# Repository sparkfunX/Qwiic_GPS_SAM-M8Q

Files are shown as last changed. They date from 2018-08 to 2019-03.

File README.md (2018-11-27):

SparkFun Ublox GPS Breakout - SAM-M8Q
===========================================================

SparkFun SAM-M8Q (https://www.sparkfun.com/products/15106)

[*SparkFun Ublox GPS Breakout - SAM-M8Q (SPX-15106)*](https://www.sparkfun.com/products/15106)

The SAM-M8Q is a small GNSS receiver from Ublox with an impressive number of configurations and the ability to communicate over I2C. 

Repository Contents
-------------------

* **/Documents** - Ublox datasheets and various whitepapers around RTK
* **/Hardware** - Eagle files

Documentation
--------------

* **[Installing an Arduino Library Guide](https://learn.sparkfun.com/tutorials/installing-an-arduino-library)** - Basic information on how to install an Arduino library.
* **[Arduino Library](https://github.com/sparkfun/SparkFun_Ublox_Arduino_Library)** - Arduino Library for the SparkFun Ublox GPS-RTK.

License Information
-------------------

This product is _**open source**_! 

Various bits of the code have different licenses applied. Anything SparkFun wrote is beerware; if you see me (or any other SparkFun employee) at the local, and you've found our code helpful, please buy us a round!

Please use, reuse, and modify these files as you see fit. Please maintain attribution to SparkFun Electronics and release anything derivative under the same license.

Distributed as-is; no warranty is given.

- Your friends at SparkFun.

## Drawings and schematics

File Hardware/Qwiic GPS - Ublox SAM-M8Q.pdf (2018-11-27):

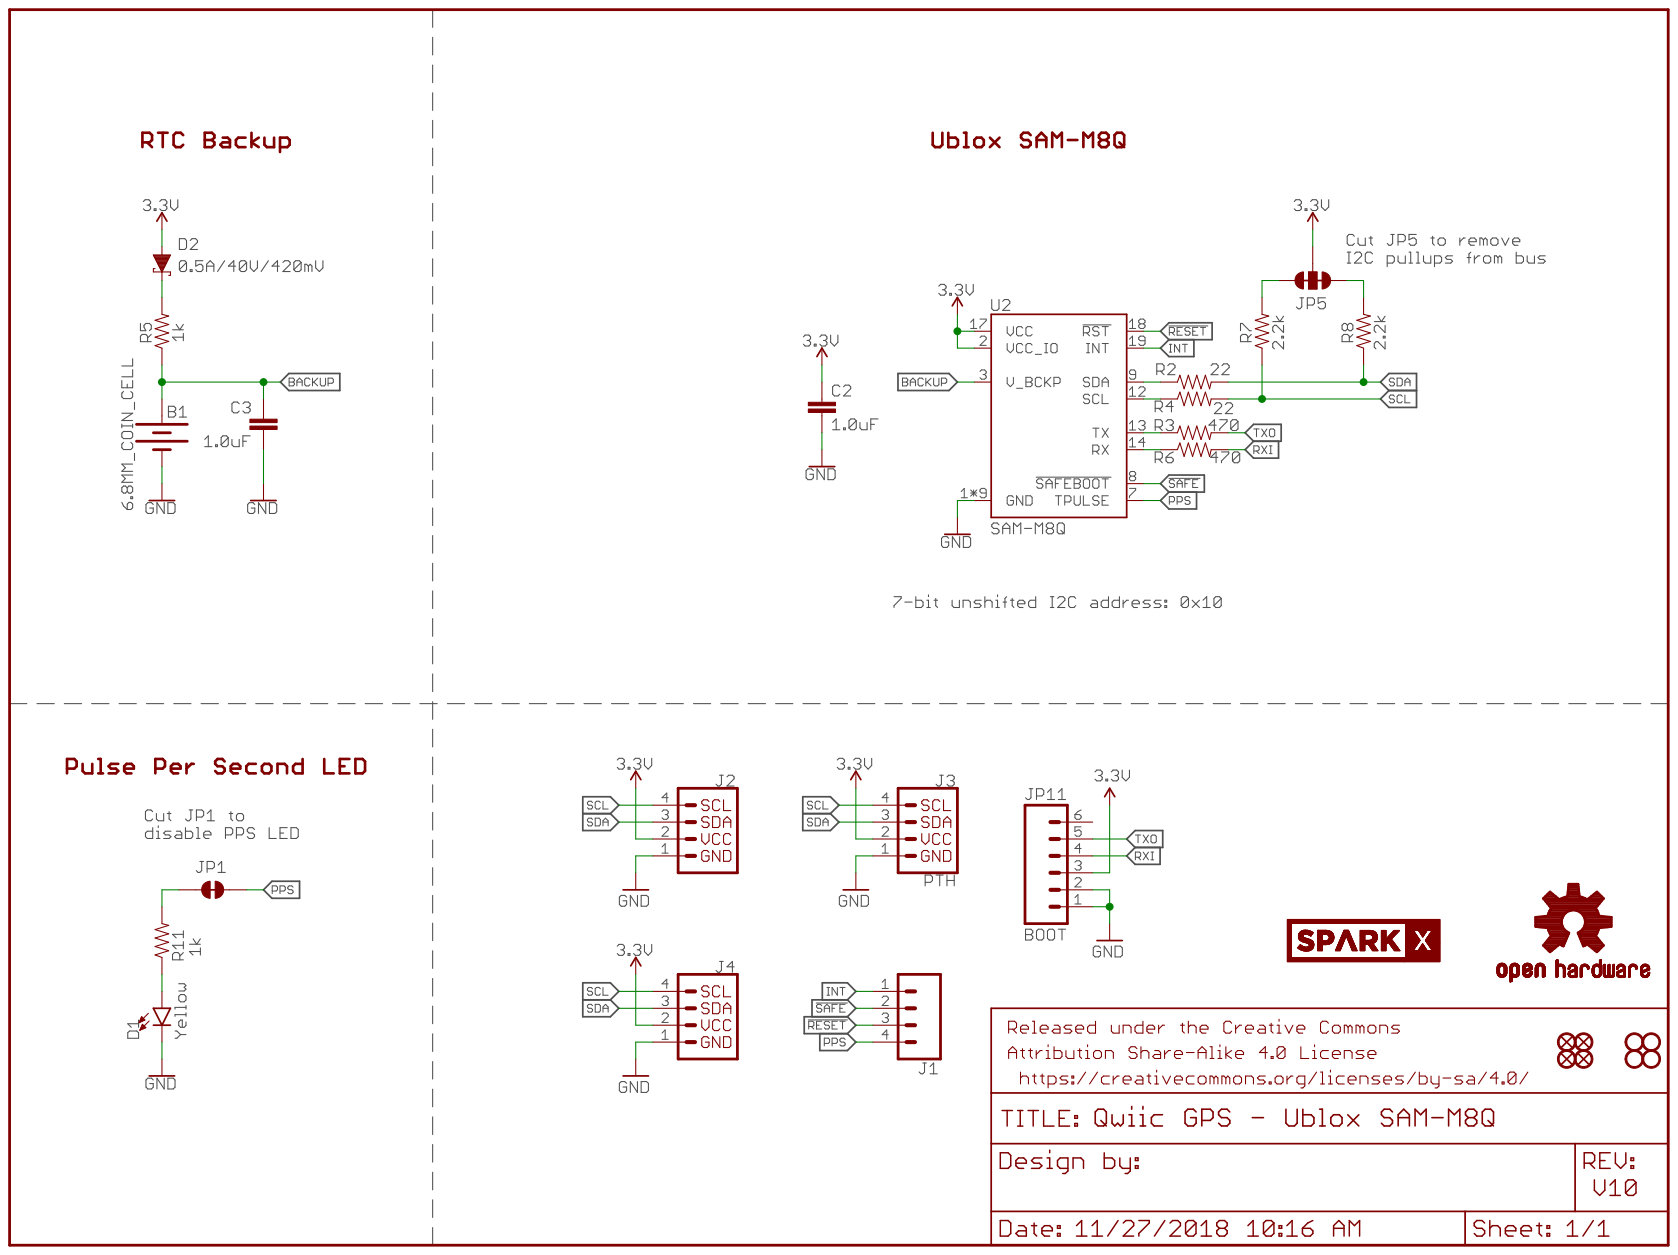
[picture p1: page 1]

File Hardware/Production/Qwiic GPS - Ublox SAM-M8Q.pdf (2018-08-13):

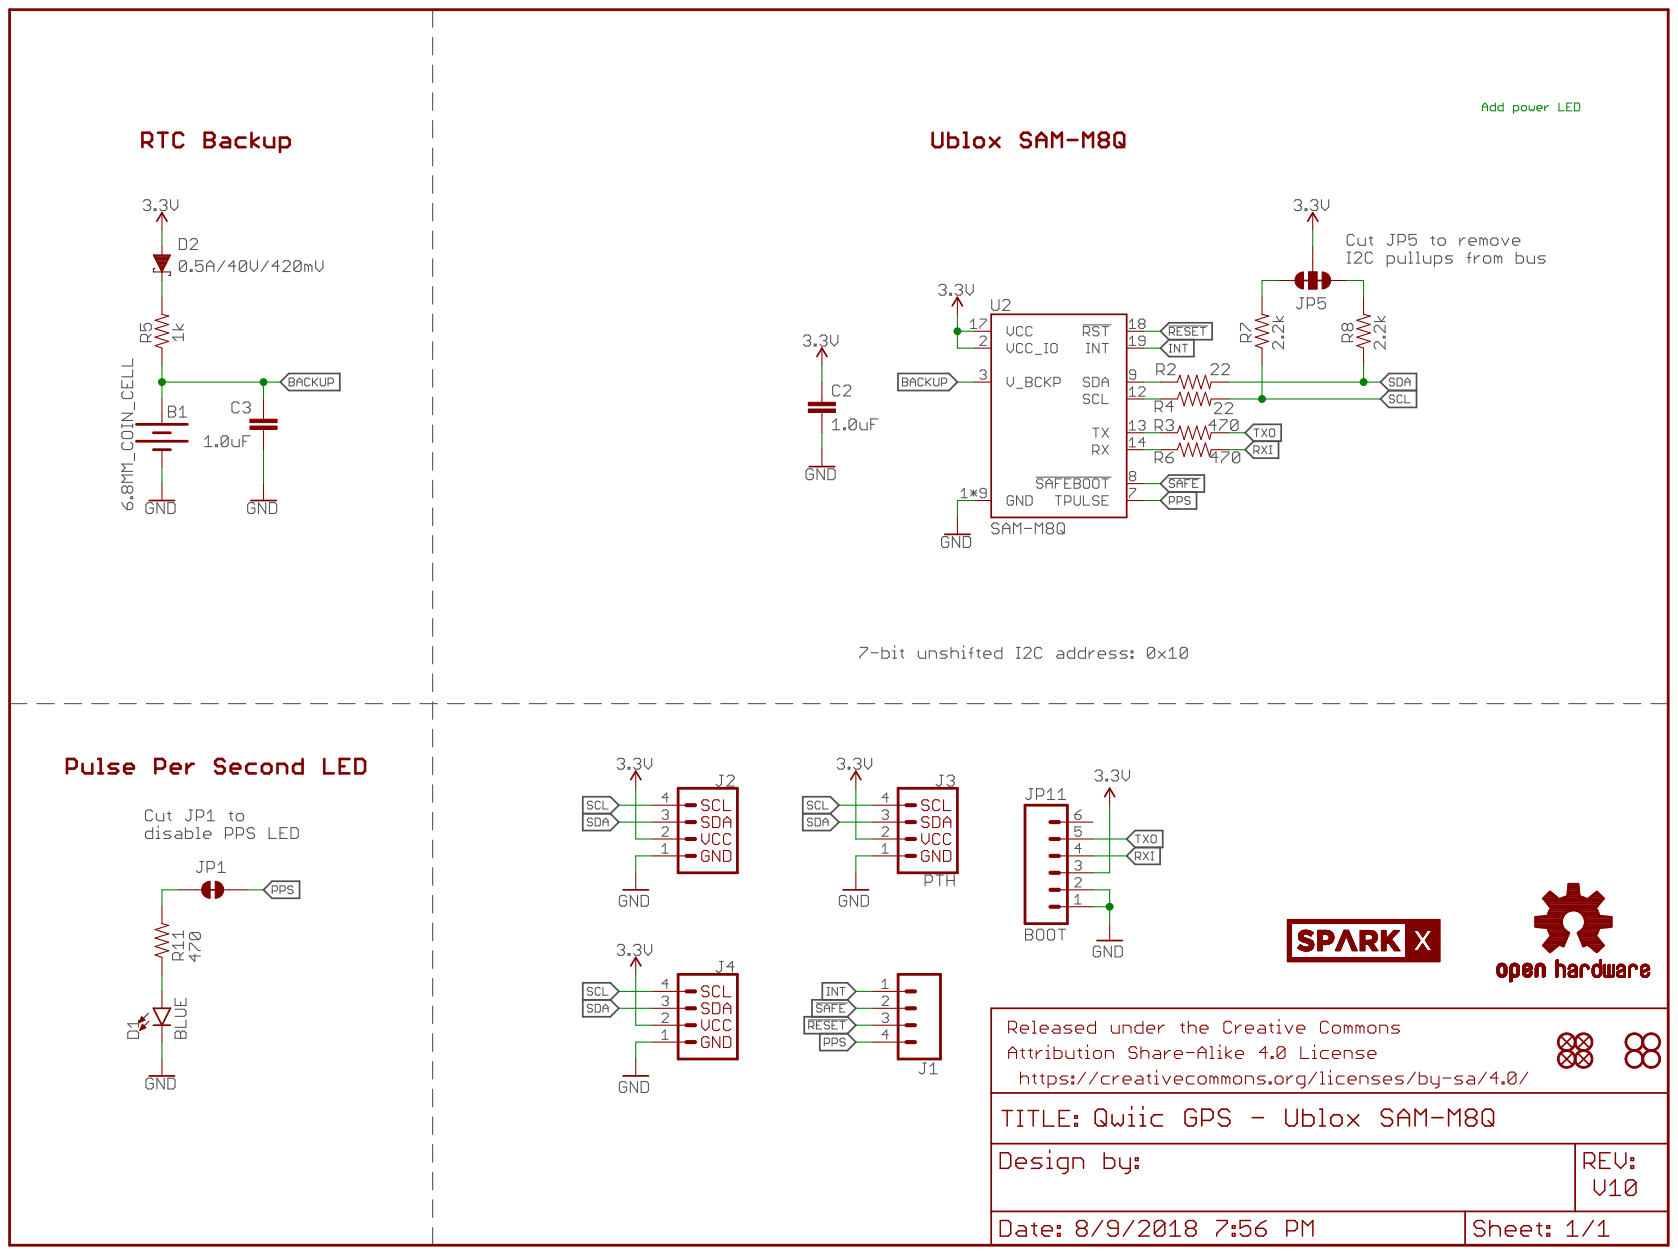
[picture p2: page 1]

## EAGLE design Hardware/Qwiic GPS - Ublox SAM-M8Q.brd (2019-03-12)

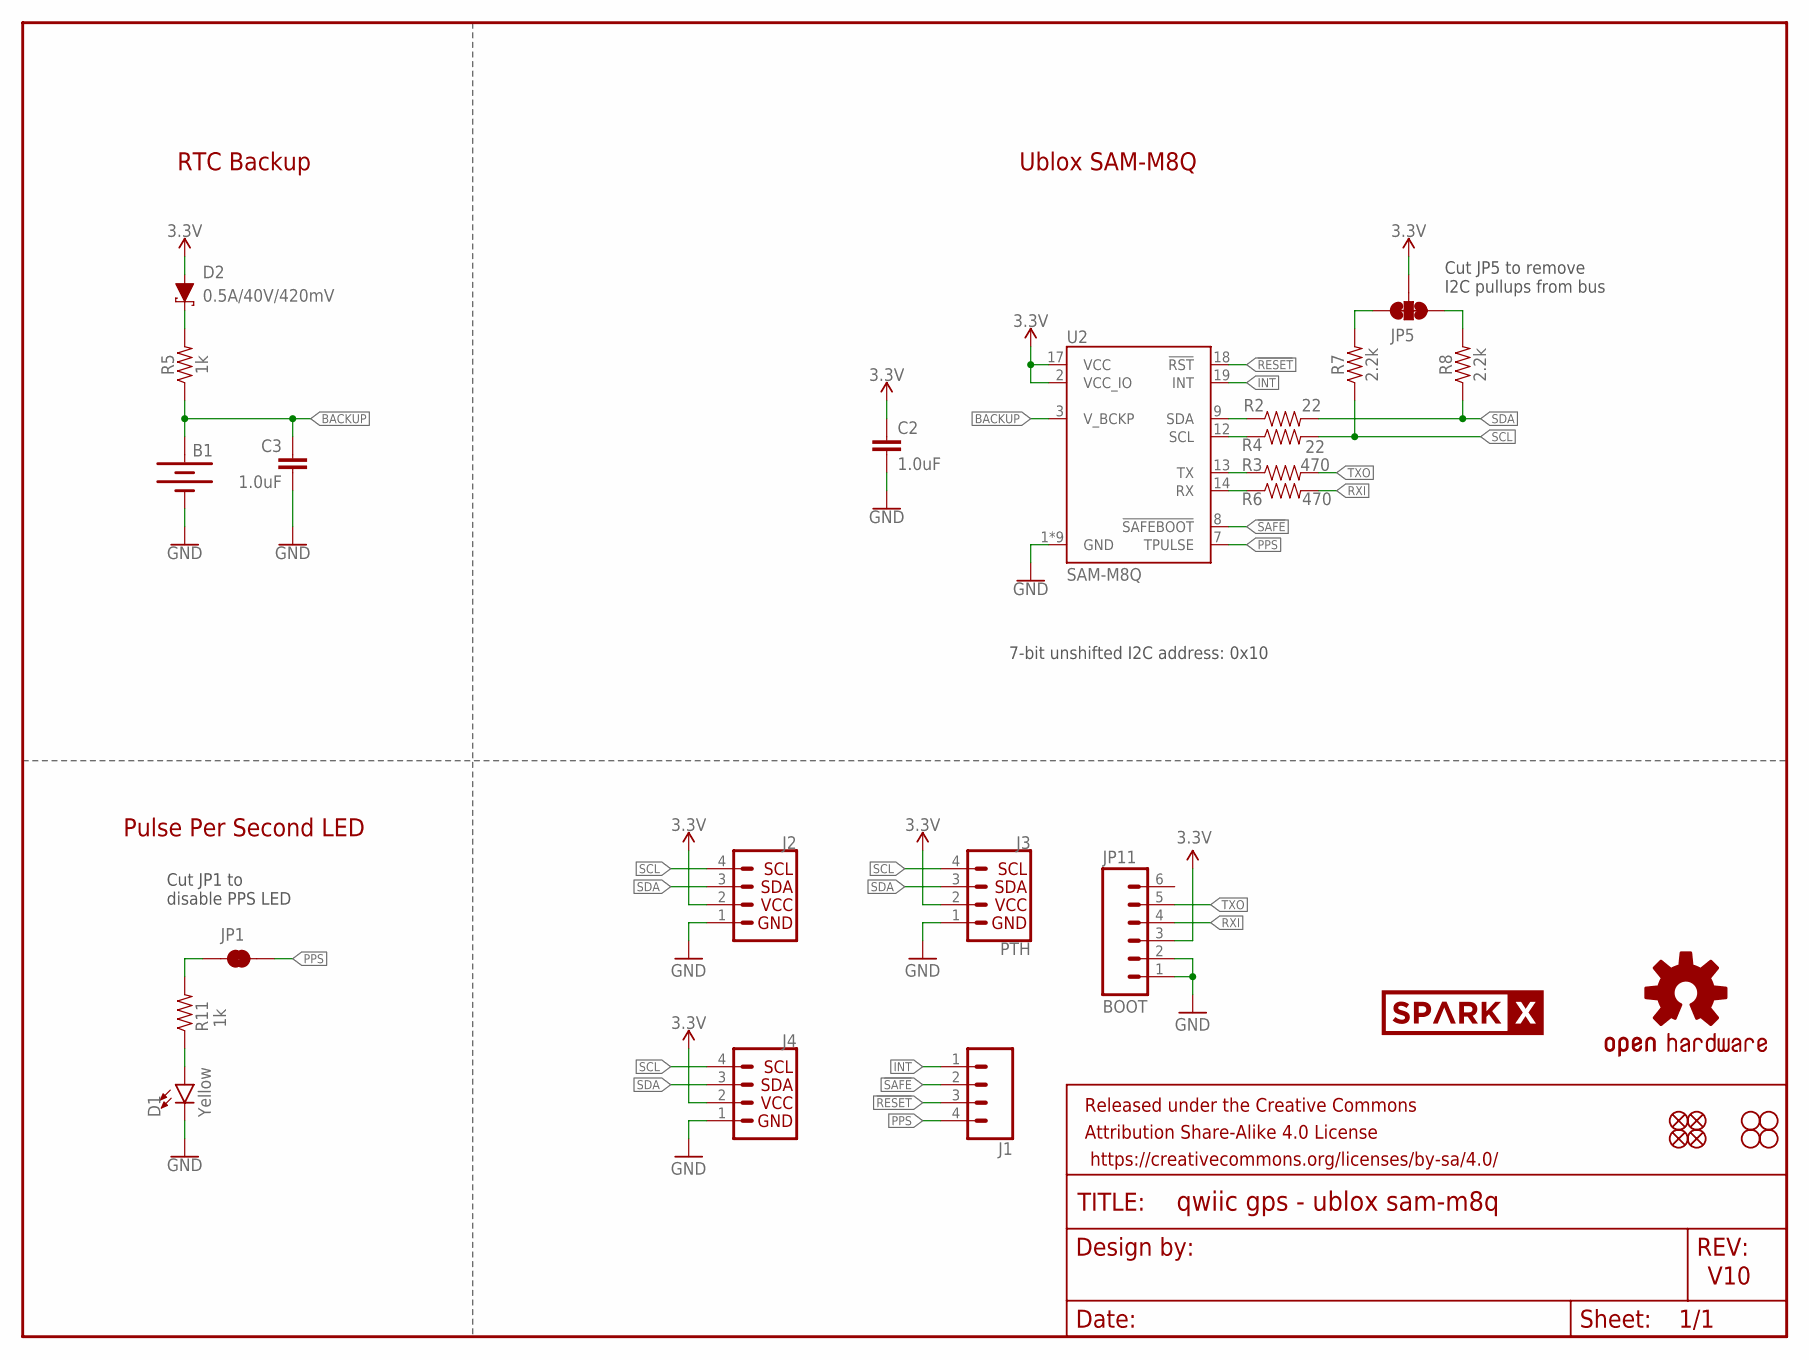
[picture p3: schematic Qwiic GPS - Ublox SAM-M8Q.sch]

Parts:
B1: 6.8MM_COIN_CELL; ML414H_IV01E
C2, C3: 1.0uF; 0603
D1: Yellow; LED-0603
D2: 0.5A/40V/420mV; SOD-323
FRAME1: FRAME-LETTER; CREATIVE_COMMONS
J1: CONN_041X04_NO_SILK; 1X04_NO_SILK
J2, J4: I2C_STANDARDQWIIC; 1X04_1MM_RA
J3: PTH; 1X04_NO_SILK
JP1: JUMPER-SMT_2_NC_TRACE_SILK; SMT-JUMPER_2_NC_TRACE_SILK
JP2, JP6, JP7, JP8: FIDUCIALUFIDUCIAL; MICRO-FIDUCIAL
JP3, JP4, JP9, JP10: STAND-OFF
JP5: JUMPER-SMT_3_2-NC_TRACE_SILK; SMT-JUMPER_3_2-NC_TRACE_SILK
JP11: BOOT; 1X06_NO_SILK
LOGO1: OSHW-LOGOMINI; OSHW-LOGO-MINI
R2, R4: 22; 0603
R3, R6: 470; 0603
R5, R11: 1k; 0603
R7, R8: 2.2k; 0603
U2: SAM-M8Q
U$31: SPARKX-LOGO4; SPARKX-MEDIUM

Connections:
3.3V: C2.1, D2.A, J2.2, J3.2 (VCC), J4.2, JP5.2, JP11.3, U2.2 (VCC_IO), U2.17 (VCC)
!RESET: J1.3, U2.18 (!RST)
!SAFE: J1.2, U2.8 (!SAFEBOOT)
BACKUP: B1.+, C3.1, R5.1, U2.3 (V_BCKP)
GND: B1.-, C2.2, C3.2, D1.C, J2.1, J3.1 (GND), J4.1, JP11.1, JP11.2, U2.1 (GND), U2.4 (GND), U2.5 (GND), U2.6 (GND), U2.10 (GND), U2.11 (GND), U2.15 (GND), U2.16 (GND), U2.20 (GND)
INT: J1.1, U2.19 (INT)
unnamed: D1.A, R11.1
unnamed: JP1.1, R11.2
unnamed: JP5.1, R8.2
unnamed: D2.C, R5.2
unnamed: JP5.3, R7.2
PPS: J1.4, JP1.2, U2.7 (TPULSE)
RXI: JP11.4, R6.2
RXLV: R6.1, U2.14 (RX)
SCL: J2.4, J3.4 (SCL), J4.4, R4.2, R7.1
SCL_LV: R4.1, U2.12 (SCL)
SDA: J2.3, J3.3 (SDA), J4.3, R2.2, R8.1
SDA_LV: R2.1, U2.9 (SDA)
TXLV: R3.1, U2.13 (TX)
TXO: JP11.5, R3.2

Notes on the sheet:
V10
7-bit unshifted I2C address: 0x10
Ublox SAM-M8Q
RTC Backup
Pulse Per Second LED
Cut JP5 to remove I2C pullups from bus
Cut JP1 to disable PPS LED

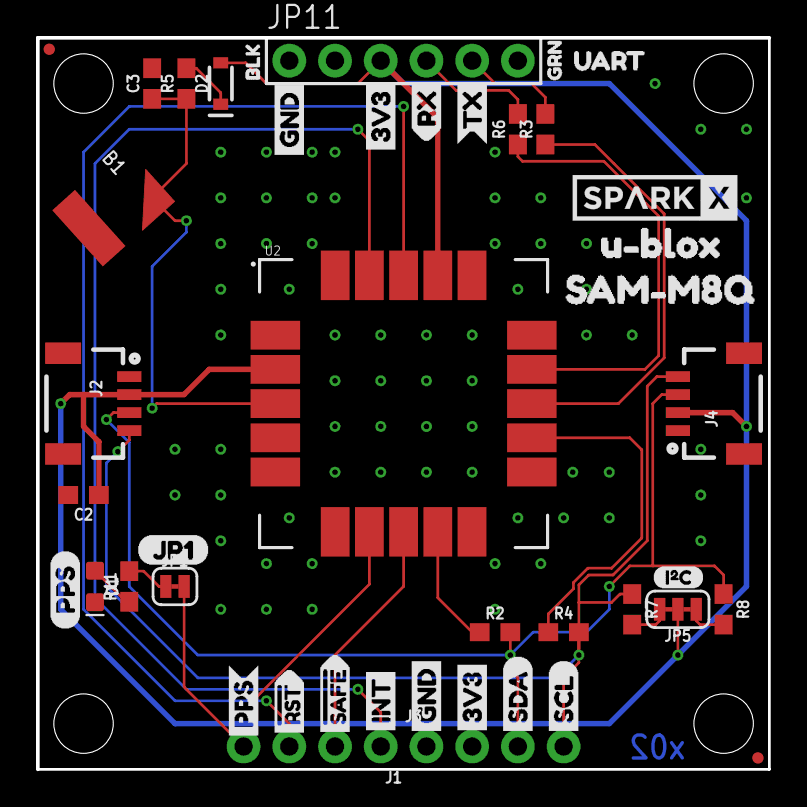
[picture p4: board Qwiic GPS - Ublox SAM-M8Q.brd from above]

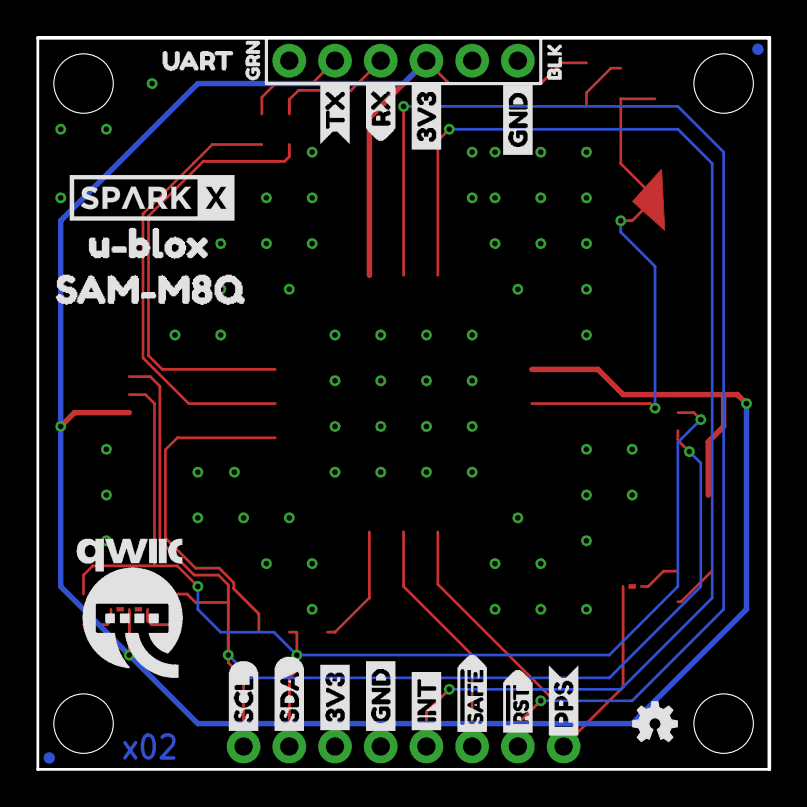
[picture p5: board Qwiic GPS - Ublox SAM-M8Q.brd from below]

Board: 2 copper layers, 40.6 x 40.6 mm, 71 parts (22 on the bottom side), 20 nets.

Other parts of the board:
U$1, U$4: SDA-[)
U$2: SPARKX-LOGO4; SPARKX-MEDIUM
U$3, U$5: SCL-[)
U$6, U$7, U$27, U$32: 3V3-04
U$8, U$9, U$33, U$34: GND-04
U$10: I_SUPER2_C-()-03
U$11, U$45: UART0
U$12, U$13: BLK1
U$14, U$17: GRN2
U$15, U$16: INT8
U$18: JP10
U$19, U$20: RX6
U$21, U$25: SAM#M8Q4
U$22, U$26: U#BLOX3
U$23, U$24: TX7
U$28: QWIIC-LOGO-LARGE
U$29: PPS0
U$35, U$36: #RST3
U$39, U$40: #SAFE1
U$43, U$44: PPS5

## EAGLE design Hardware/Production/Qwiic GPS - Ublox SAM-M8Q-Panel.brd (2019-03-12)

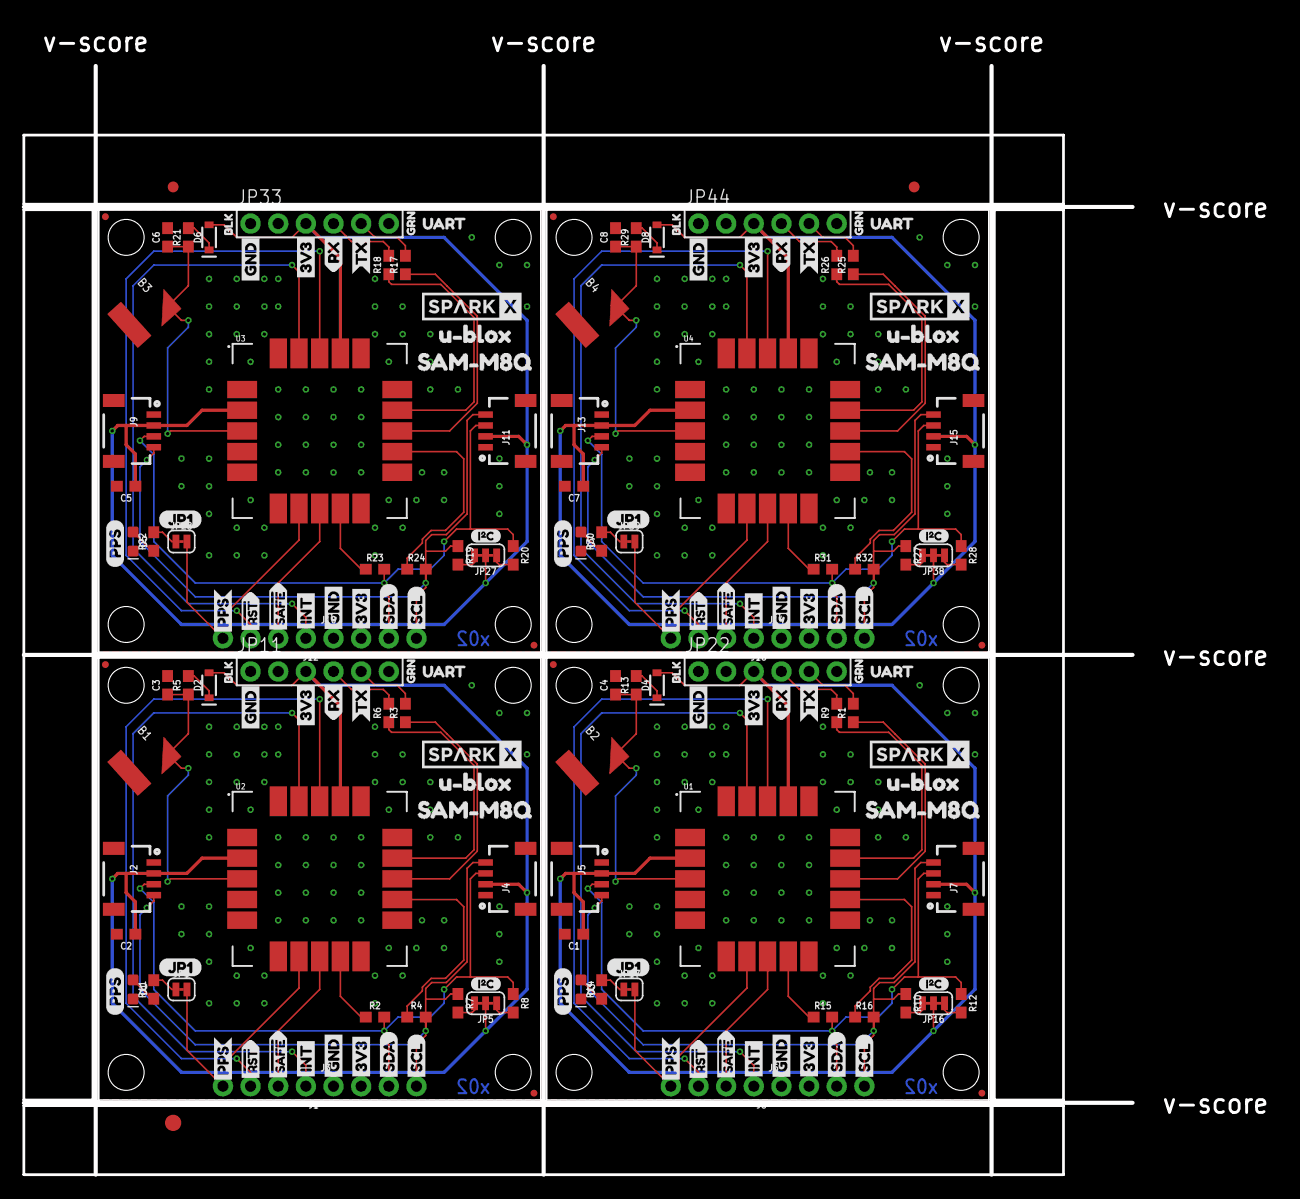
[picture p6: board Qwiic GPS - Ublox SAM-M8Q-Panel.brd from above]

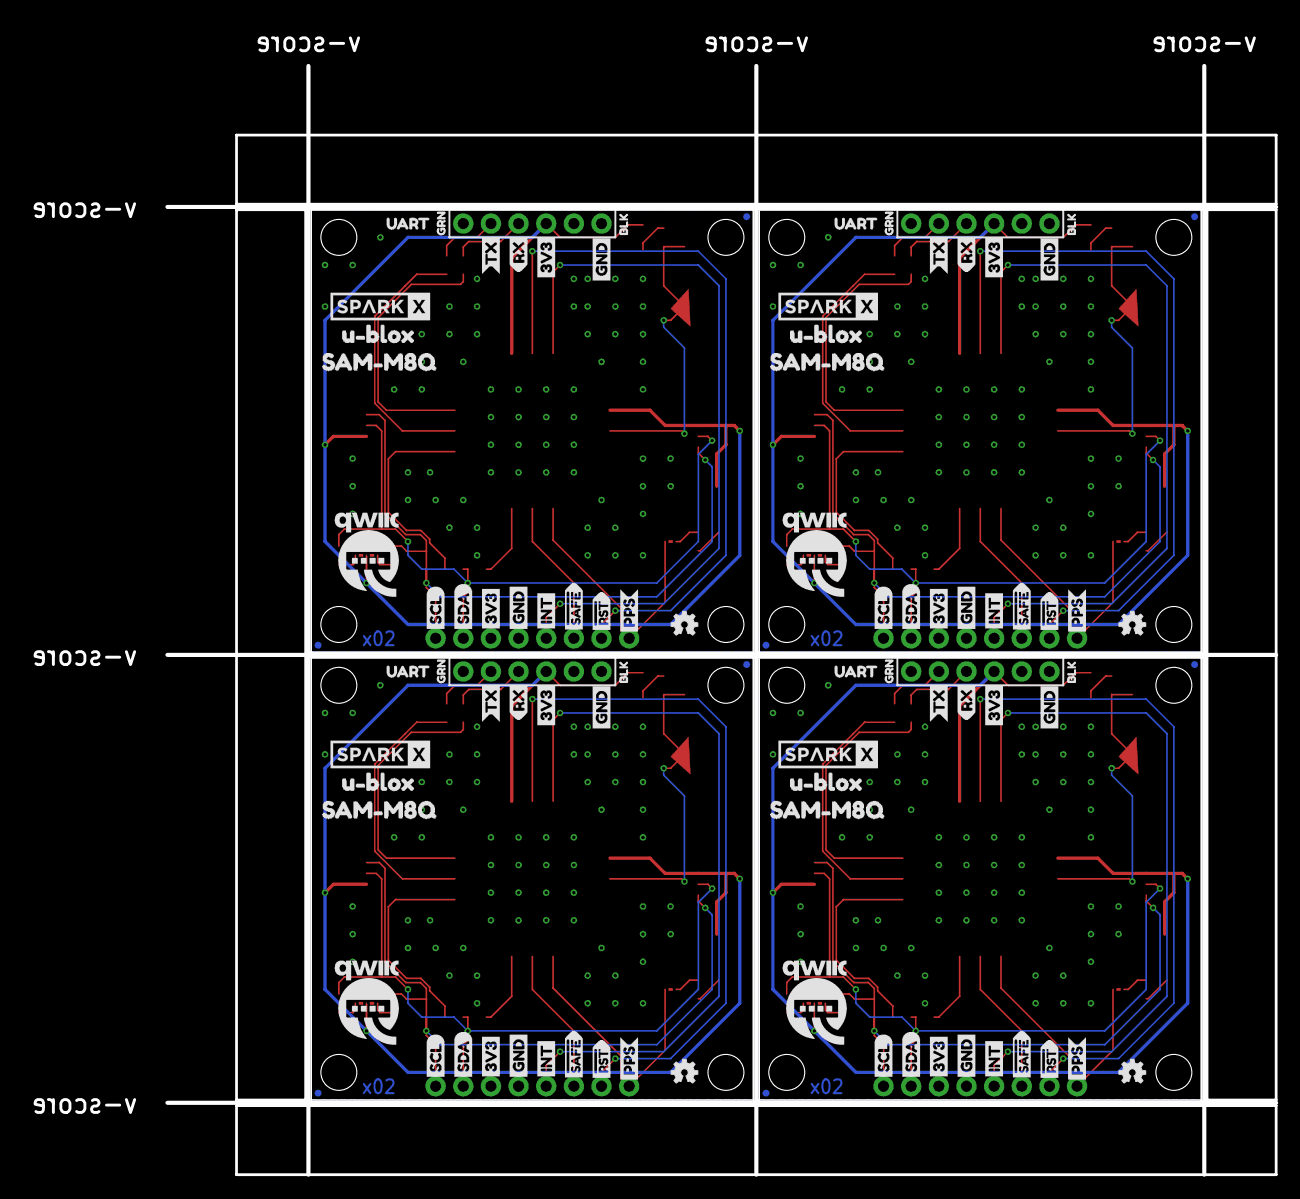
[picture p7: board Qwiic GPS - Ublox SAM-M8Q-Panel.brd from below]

Board: 2 copper layers, 101.9 x 101.9 mm, 283 parts (88 on the bottom side), 80 nets.

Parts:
B1, B2, B3, B4: 6.8MM_COIN_CELL; ML414H_IV01E
C1, C2, C3, C4, C5, C6, C7, C8: 1.0uF; 0603
D1, D3, D5, D7: Yellow; LED-0603
D2, D4, D6, D8: 0.5A/40V/420mV; SOD-323
E$1, E$2: FIDUCIAL-1X2
E$3: FIDUCIAL-1.5X3
J1, J8, J12, J16: 1X04_NO_SILK
J2, J4, J5, J7, J9, J11, J13, J15: 1X04_1MM_RA
J3, J6, J10, J14: PTH; 1X04_NO_SILK
JP1, JP17, JP28, JP39: SMT-JUMPER_2_NC_TRACE_SILK
JP2, JP6, JP7, JP8, JP14, JP15, JP18, JP19, JP25, JP26, JP29, JP30, JP36, JP37, JP40, JP41: FIDUCIALUFIDUCIAL; MICRO-FIDUCIAL
JP3, JP4, JP9, JP10, JP12, JP13, JP20, JP21, JP23, JP24, JP31, JP32, JP34, JP35, JP42, JP43: STAND-OFF
JP5, JP16, JP27, JP38: SMT-JUMPER_3_2-NC_TRACE_SILK
JP11, JP22, JP33, JP44: BOOT; 1X06_NO_SILK
LOGO1, LOGO2, LOGO3, LOGO4: OSHW-LOGOMINI; OSHW-LOGO-MINI
R1, R3, R6, R9, R17, R18, R25, R26: 470; 0603
R2, R4, R15, R16, R23, R24, R31, R32: 22; 0603
R5, R11, R13, R14, R21, R22, R29, R30: 1k; 0603
R7, R8, R10, R12, R19, R20, R27, R28: 2.2k; 0603
U1, U2, U3, U4: SAM-M8Q
U$1, U$4, U$30, U$38, U$81, U$83, U$121, U$123: SDA-[)
U$2, U$31, U$61, U$62, U$101, U$102, U$141, U$142: SPARKX-LOGO4; SPARKX-MEDIUM
U$3, U$5, U$37, U$41, U$82, U$84, U$122, U$124: SCL-[)
U$6, U$7, U$27, U$32, U$42, U$46, U$63, U$64, U$85, U$86, U$103, U$104, U$125, U$126, U$143, U$144: 3V3-04
U$8, U$9, U$33, U$34, U$47, U$48, U$65, U$66, U$87, U$88, U$105, U$106, U$127, U$128, U$145, U$146: GND-04
U$10, U$49, U$89, U$129: I_SUPER2_C-()-03
U$11, U$45, U$73, U$74, U$113, U$114, U$153, U$154: UART0
U$12, U$13, U$75, U$76, U$115, U$116, U$155, U$156: BLK1
U$14, U$17, U$77, U$78, U$117, U$118, U$157, U$158: GRN2
U$15, U$16, U$50, U$51, U$90, U$91, U$130, U$131: INT8
U$18, U$79, U$119, U$159: JP10
U$19, U$20, U$52, U$53, U$92, U$93, U$132, U$133: RX6
U$21, U$25, U$54, U$59, U$94, U$99, U$134, U$139: SAM#M8Q4
U$22, U$26, U$57, U$58, U$97, U$98, U$137, U$138: U#BLOX3
U$23, U$24, U$55, U$56, U$95, U$96, U$135, U$136: TX7
U$28, U$80, U$120, U$160: QWIIC-LOGO-LARGE
U$29, U$60, U$100, U$140: PPS0
U$35, U$36, U$67, U$68, U$107, U$108, U$147, U$148: #RST3
U$39, U$40, U$69, U$70, U$109, U$110, U$149, U$150: #SAFE1
U$43, U$44, U$71, U$72, U$111, U$112, U$151, U$152: PPS5

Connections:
3.3V: C2.1, D2.A, J2.2, J3.2, J4.2, JP5.2, JP11.3, U2.2, U2.17
3.3V1: C1.1, D4.A, J5.2, J6.2, J7.2, JP16.2, JP22.3, U1.2, U1.17
3.3V2: C5.1, D6.A, J9.2, J10.2, J11.2, JP27.2, JP33.3, U3.2, U3.17
3.3V3: C7.1, D8.A, J13.2, J14.2, J15.2, JP38.2, JP44.3, U4.2, U4.17
!RESET: J1.3, U2.18
!RESET1: J8.3, U1.18
!RESET2: J12.3, U3.18
!RESET3: J16.3, U4.18
!SAFE: J1.2, U2.8
!SAFE1: J8.2, U1.8
!SAFE2: J12.2, U3.8
!SAFE3: J16.2, U4.8
BACKUP: B1.+, C3.1, R5.1, U2.3
BACKUP1: B2.+, C4.1, R13.1, U1.3
BACKUP2: B3.+, C6.1, R21.1, U3.3
BACKUP3: B4.+, C8.1, R29.1, U4.3
GND: B1.-, C2.2, C3.2, D1.C, J2.1, J3.1, J4.1, JP11.1, JP11.2, U2.1, U2.4, U2.5, U2.6, U2.10, U2.11, U2.15, U2.16, U2.20
GND1: B2.-, C1.2, C4.2, D3.C, J5.1, J6.1, J7.1, JP22.1, JP22.2, U1.1, U1.4, U1.5, U1.6, U1.10, U1.11, U1.15, U1.16, U1.20
GND2: B3.-, C5.2, C6.2, D5.C, J9.1, J10.1, J11.1, JP33.1, JP33.2, U3.1, U3.4, U3.5, U3.6, U3.10, U3.11, U3.15, U3.16, U3.20
GND3: B4.-, C7.2, C8.2, D7.C, J13.1, J14.1, J15.1, JP44.1, JP44.2, U4.1, U4.4, U4.5, U4.6, U4.10, U4.11, U4.15, U4.16, U4.20
INT: J1.1, U2.19
INT1: J8.1, U1.19
INT2: J12.1, U3.19
INT3: J16.1, U4.19
unnamed: JP16.1, R12.2
unnamed: D1.A, R11.1
unnamed: JP16.3, R10.2
unnamed: JP1.1, R11.2
unnamed: JP5.1, R8.2
unnamed: D2.C, R5.2
unnamed: D3.A, R14.1
unnamed: JP5.3, R7.2
unnamed: JP17.1, R14.2
unnamed: D4.C, R13.2
unnamed: JP27.1, R20.2
unnamed: JP27.3, R19.2
unnamed: D5.A, R22.1
unnamed: JP28.1, R22.2
unnamed: D6.C, R21.2
unnamed: JP38.1, R28.2
unnamed: JP38.3, R27.2
unnamed: D7.A, R30.1
unnamed: JP39.1, R30.2
unnamed: D8.C, R29.2
PPS: J1.4, JP1.2, U2.7
PPS1: J8.4, JP17.2, U1.7
PPS2: J12.4, JP28.2, U3.7
PPS3: J16.4, JP39.2, U4.7
RXI: JP11.4, R6.2
RXI1: JP22.4, R9.2
RXI2: JP33.4, R18.2
RXI3: JP44.4, R26.2
RXLV: R6.1, U2.14
RXLV1: R9.1, U1.14
RXLV2: R18.1, U3.14
RXLV3: R26.1, U4.14
SCL: J2.4, J3.4, J4.4, R4.2, R7.1
SCL1: J5.4, J6.4, J7.4, R10.1, R16.2
SCL2: J9.4, J10.4, J11.4, R19.1, R24.2
SCL3: J13.4, J14.4, J15.4, R27.1, R32.2
SCL_LV: R4.1, U2.12
SCL_LV1: R16.1, U1.12
SCL_LV2: R24.1, U3.12
SCL_LV3: R32.1, U4.12
SDA: J2.3, J3.3, J4.3, R2.2, R8.1
SDA1: J5.3, J6.3, J7.3, R12.1, R15.2
SDA2: J9.3, J10.3, J11.3, R20.1, R23.2
SDA3: J13.3, J14.3, J15.3, R28.1, R31.2
SDA_LV: R2.1, U2.9
SDA_LV1: R15.1, U1.9
SDA_LV2: R23.1, U3.9
SDA_LV3: R31.1, U4.9
TXLV: R3.1, U2.13
TXLV1: R1.1, U1.13
TXLV2: R17.1, U3.13
TXLV3: R25.1, U4.13
TXO: JP11.5, R3.2
TXO1: JP22.5, R1.2
TXO2: JP33.5, R17.2
TXO3: JP44.5, R25.2

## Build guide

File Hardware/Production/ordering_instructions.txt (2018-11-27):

panel size, 96x96mm
PCB thickness, 1.6mm
number of layers, 2
soldermask color, Black
silkscreen color, White
oz copper, 1oz
finish, HASL lead free
stencils, top
pcs per panel, 4

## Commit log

2018-11-27 Removing single unit files. Removing notes from schematic.
    [Qwiic GPS - Ublox SAM-M8Q - EAGLE ARRRG.brd, Qwiic GPS - Ublox SAM-M8Q - EAGLE ARRRG.sch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]
2019-03-12 Updated battery footprint
    Footprint for the battery is now for the reflowable version
    [Qwiic GPS - Ublox SAM-M8Q-Panel.GBL, Qwiic GPS - Ublox SAM-M8Q-Panel.GBO, Qwiic GPS - Ublox SAM-M8Q-Panel.GBS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]

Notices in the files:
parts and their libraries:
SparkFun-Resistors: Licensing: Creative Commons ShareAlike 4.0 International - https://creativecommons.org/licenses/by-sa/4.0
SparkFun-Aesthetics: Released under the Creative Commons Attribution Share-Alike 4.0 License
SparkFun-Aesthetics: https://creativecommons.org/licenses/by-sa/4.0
